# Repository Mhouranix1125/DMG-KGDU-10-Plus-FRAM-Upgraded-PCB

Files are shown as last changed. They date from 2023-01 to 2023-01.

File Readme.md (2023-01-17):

### Welcome! PLEASE READ EVERYTHING!

First: Shoutout to HDR. His work was extremely vital in completing this project. Take a look at his github and check out some of the cool projects he has worked on!

[HDR's Github](https://github.com/HDR)

Second: You do this entire transfer at your own risk. I am not responsible for anything that happens to your game as a result of taking on this project. This is not a beginner task, and should definitely not be taken on as a first-time solder project.  I am not affiliated with any of the companies mentioned here. I do not do this for profit. This is just a neat little thing I decided to work on. 

This project is open source. Users may use this work to iterate, or improve upon it. In doing so, please make sure you follow the Creative Common License linked below. Out of respect for HDR. Do not be a bad actor. your compliance is expected, and appreciated. DMG-KGDU-10 is an original Nintendo PCB design. I take no credit for that. 

[Creative Commons License](https://creativecommons.org/licenses/by-nc-sa/4.0/)

### What is this project about?

In simple terms - This project is an upgraded replacement circuit board for games like Pokémon Gold, Silver, and Crystal. This board utilizes FRAM instead of SRAM so you can save your games without the need for a battery. The battery is still required for the real time clock (RTC) to function. But the good news is you will not lose any save data when the battery does die. This also features a battery retainer, so you can place a CR2025 into the slot without the need for solder tabs. This also enables you to use BRAND NAME batteries. The batteries most users buy for their games have those yellow rings around them and are absolutely terrible and volatile. Brand Name batteries are a more reliable choice and will last MUCH longer. This board was designed with the United States version of the games in mind. I created this board for a few reasons. 

1. SRAM is annoying and I hate that my save data was at the mercy of a simple coin cell battery. This fixes that and allows for a very clean and professional looking mod without wires running all over the place.

2. I see tons of reddit posts of people posting their Pokemon Gold, Silver, or Crystal games in less than stellar condition. Sure, you can use jumper wires, and if you like that, it's all you. Some are beyond repair due to corrosion, broken traces, or just problems that aren't solvable. If the ROM IC, and MBC3 mapper are in good shape. This board will definitely save your game. Your games are not broken if your circuit board is in bad shape!

3. To learn.

### How can I get my hands on these boards?

In order to get your hands on these boards, you will need to download this project zip, or clone it using GIT. One of the files labeled DMG-KGDU-10+_Gerber.zip Is the completed output of the circuit board. There are a few websites you can upload this to in order to get these boards made. they are not that expensive. These are the ones I use often. But feel free to use another if you’re comfortable with them. 

Note: PLEASE ORDER THESE BOARDS WITH THE FOLLOWING SPECIFICATIONS. IF YOU DO NOT ORDER THEM CORRECTLY, THEY WILL NOT WORK, OR WILL NOT FIT!

* Thickness: 0.8mm
* Color: Your choice! Have fun!
* Surface Finish: (ENIG or Immersion Gold. They’re the same thing) , or Hard Gold (expensive). DO NOT USE ANY OTHER OPTION. 
* Castellated Holes: No
* Copper Weight: 1oz is fine. 2oz is nice but not needed.
* Golden Fingers: Yes 
* 45° finger chamfered

1. [JLCPCB:](https://jlcpcb.com/)

o This company is based in China, and has very good pricing on boards so long as you choose either green or purple. I find the best bang for your buck to be 10 boards as it's not that much more expensive than 5.

2. [Elecrow:](https://www.elecrow.com/)

o This company is based in China, the pricing is great, and pricing is similar to JLCPCB and seems consistent across all colors. So I love these guys quite a bit. 

o Note: If using Elecrow, you will need to send them an email to specify that you want Golden Fingers, and beveled 45° finger chamfered. Just give them your order number after you place it. 

3. [Osh Park:](https://oshpark.com/shared_projects/EM2j1Td4)

o Osh Park is a USA based company. Their online gerber viewer and order process is very easy. But your options are very limited. You can only get your boards in their signature deep purple color, which are quite nice. They’re also the most expensive. Their quality is good. You get less PCB’s for your money, and I noticed that it could still take a while for them to come in.

o When you order, choose the option that says: 2 oz copper, 0.8mm thickness and you should be all set. Their ordering process is more streamlined. 

### Materials

You will need the following materials to complete this build. Feel free to source these from wherever you’d like. I recommend [Digikey](https://digikey.com), or [Mouser](https://mouser.com) for most parts. just make sure the sizes for the capacitors and resistors are correct. Double check everything. 

**Bill Of Materials:**

| Reference | Part | Description | Type |
|-|-|-|-|
| U1 | Original ROM | The lower Right chip. This is the chip that holds your game and is needed from the original board. | 44 Pins |
| U2 | MBC3 | Memory Bank Controller. You can only get this from an original Cartridge | LQFP-32 |
| U3 | FM18W08 | 256kbit FRAM | SOIC-28 |
| U4 | BA6129AF | Battery Reset IC. | Get From Original Cartridge or AliExpress | SOIC-8 |
| U5 | 74LVC1G32GV,125 | 2-input OR Gate | TSOP-5 |
| C1, C2, C3, C6, C7 | CL10B104KO8NNNC | 0.1uF Capacitor | 0603 |
| C4, C5 | CL10C150JB8NNNC | 15pF Capacitor | 0603 |
| R1 | RC0603FR-07330KL | 330K Ω Resistor | 0603 |
| R2 | RC0603FR-0710KL | 10K Ω Resistor | 0603 |
| R3 | RC0603FR-071KL | 1K Ω Resistor | 0603 |
| X1 | R26-32.768-12.5-10PPM 20PPM seems to work fine as well. | 32.768 kHz Crystal. | Buy or get from original Cartridge |
| RTC Crystal | Batt 2025 | BK-6219-TR | CR2025 Battery Retainer | Battery Retainer |

Some Tips

1). This should not be your first major solder project. Do not attempt to do this without any practice, or you risk ruining your game. 

2). Everything is pretty straight forward. Make sure you’re good with working on small components. Capacitors and resistors are not easy to solder if you’re new to this. Solder paste and hot air can help you out a lot with that process. 

3). The CR2025 battery may sometimes may not make amazing contact with the large circle pad. This is because it is ever so slightly recessed into the board. This can be fixed in a variety of ways. Super easy, and is pretty much a non issue if you just follow one of the following two ways.

My way of solving this issue is cutting out a thin piece of nickel strip (I try to make it circular in shape, and a bit smaller than the edges of the circle pad. And I lay it down flat and solder it in place before installing the BK-6219-TR retainer. Make sure you solder in the retainer so you can place the battery in from the top side of the board. If you do it upside down, getting the battery in will be annoying because the ROM IC gets in the way. 

Another way, if you don’t want to cover the pad with solder is Makhos way. Makho uses a piece of copper tape on the circle pad, rather than soldering in the nickel strip that I use. It’s nice if you don’t want to get solder on the circle pad. I personally don’t mind but the choice is yours. 

Good luck! Be sure to post your successes, and feel free to ask me any questions!

### Images

# Front

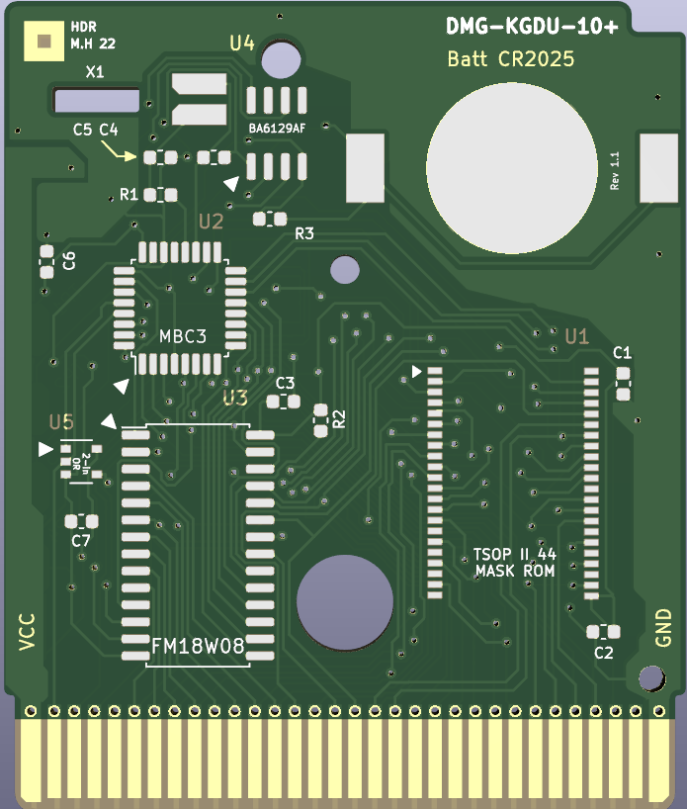
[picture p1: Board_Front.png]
Front


# Back

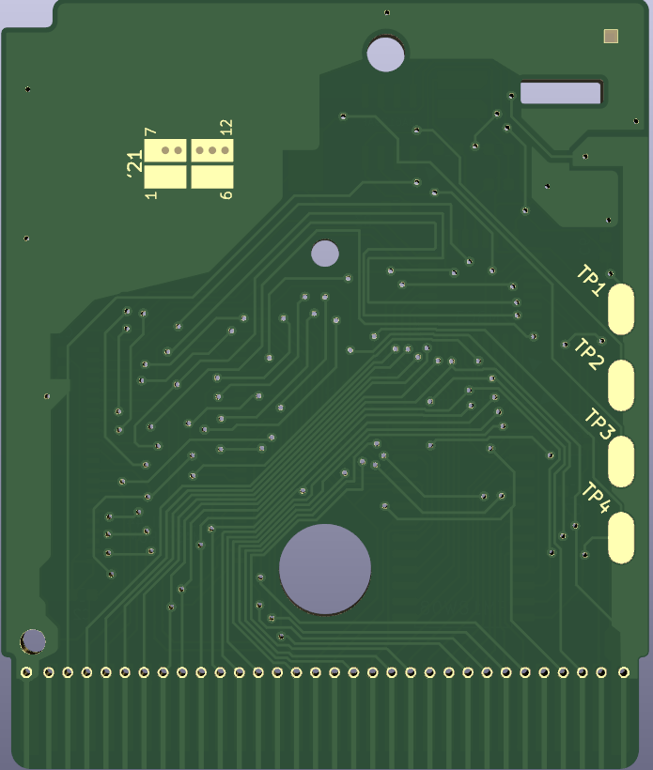
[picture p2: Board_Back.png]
Back


### Changes

Rev 1.1 
- Removed R1 Jumper Resistor. It was not needed.
- Added Text for some parts to help with clarity. The BOM should still be the ultimate source for info. 
- Moved a few capacitors around so they're easier to manage.
- Moved R3 so it would be easier to manage once the battery retainer is soldered in if need be.
- General cleanup.

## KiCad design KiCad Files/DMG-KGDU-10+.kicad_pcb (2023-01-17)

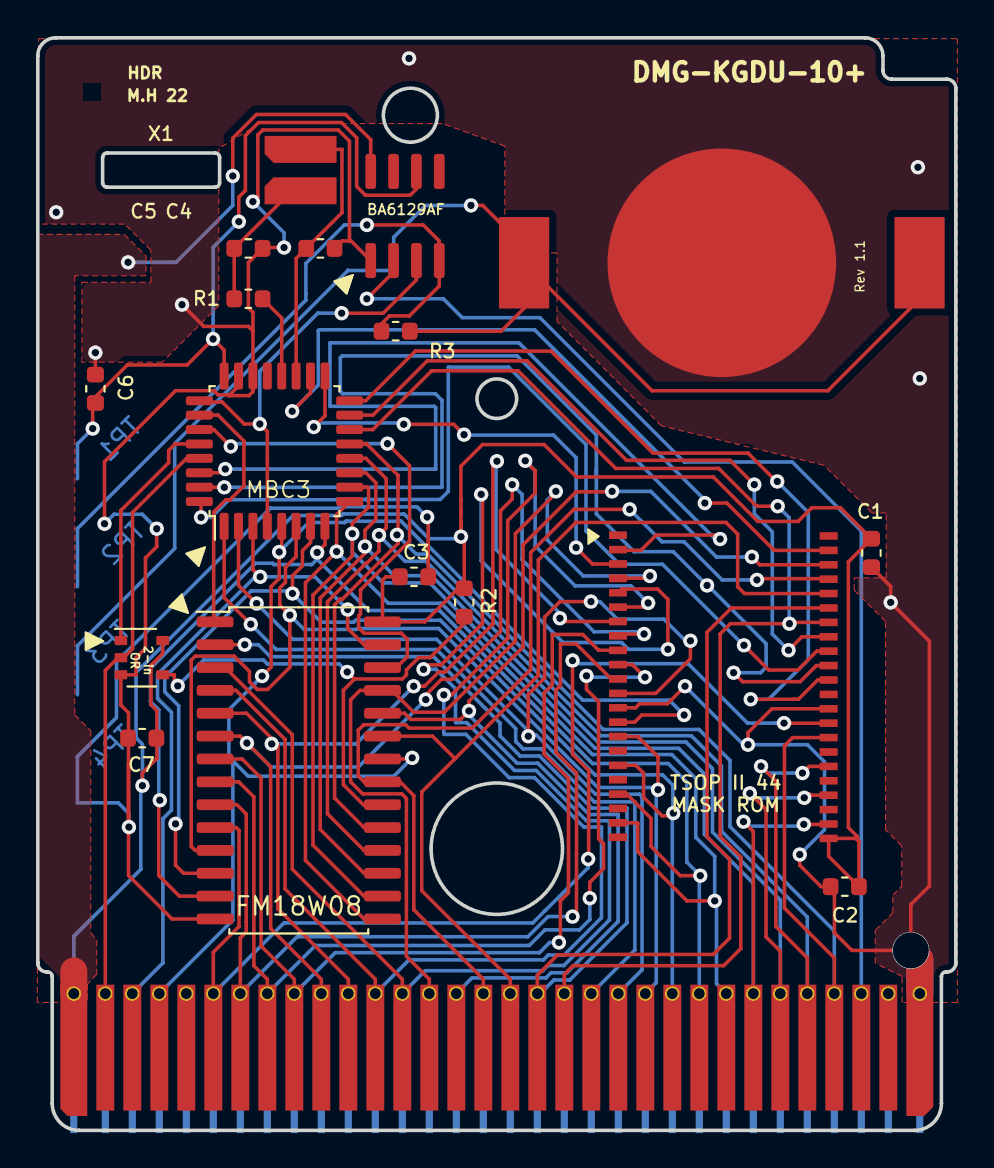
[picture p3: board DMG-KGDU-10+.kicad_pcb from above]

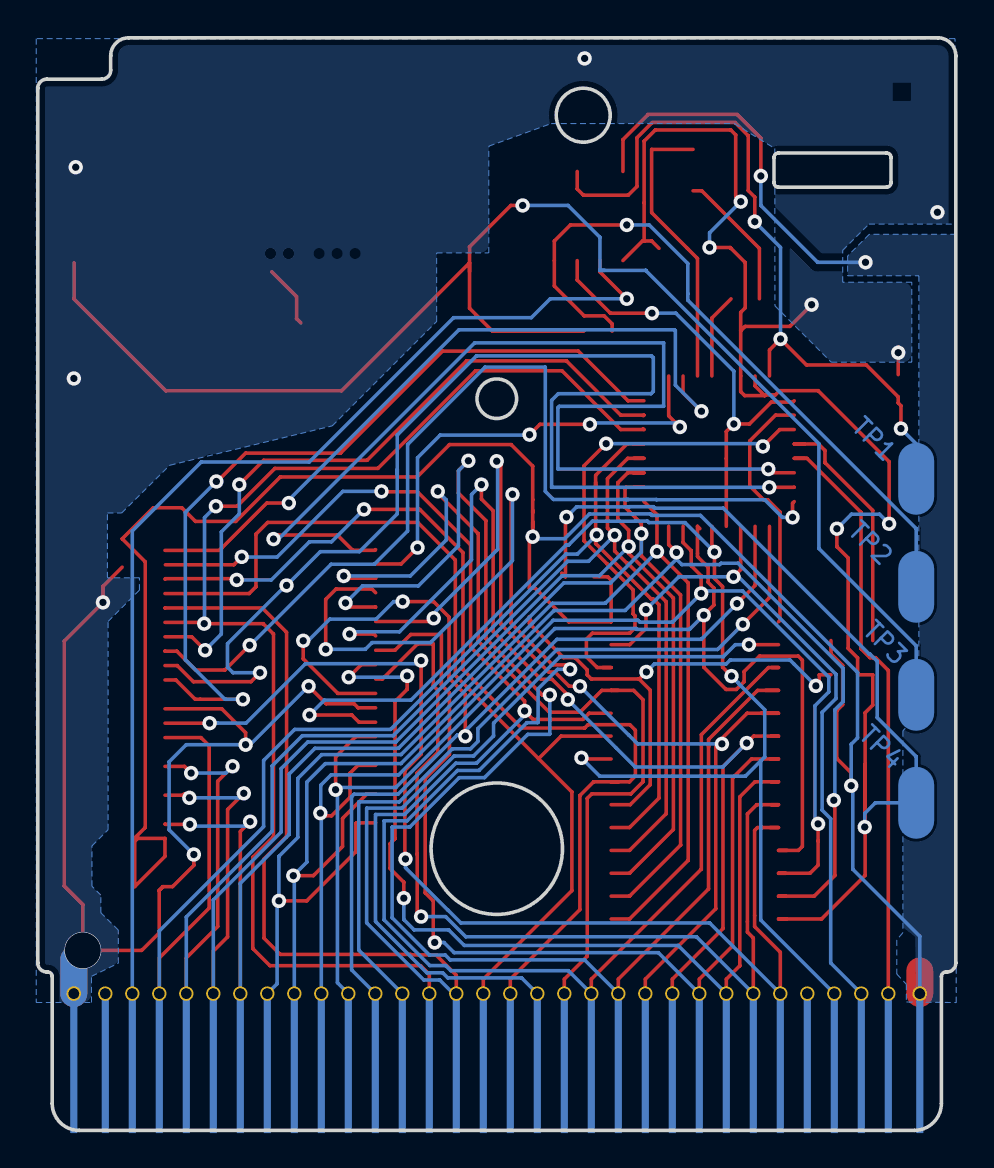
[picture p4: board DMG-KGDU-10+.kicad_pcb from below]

Board: 2 copper layers, 51.0 x 60.7 mm, 25 parts (5 on the bottom side), 48 nets.

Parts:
B1: Battery_Cell; BK-6219-TR
C1, C2, C3, C6, C7: 0.1 uF; C_0603_1608Metric
C4, C5: 15 pF; C_0603_1608Metric
GNDPAD1: Nintendo_3x3_GNDPad
L0: CASTELLATIONS TSOP-II 22P; 22_SMD_PADs
PAD*: GBA-ProductionIndicator
R0: CASTELLATIONS TSOP-II 22P; 22_SMD_PADs
R1: 330Kohm; R_0603_1608Metric
R2: 10 Kohm; R_0603_1608Metric
R3: 1 Kohm; R_0603_1608Metric
TP1: RTC_VOUT; GameBoy_Testpoint
TP2: Battery_Positive_After_Resistor; GameBoy_Testpoint
TP3: Battery_Positive; GameBoy_Testpoint
TP4: Ground; GameBoy_Testpoint
U0: CartBus; GameBoy_GamePak_CGB-002_P1.50mm_Edge
U2: MBC3
U3: FM18W08; SOIC-28W_7.5x17.9mm_P1.27mm
U4: BA6129AF; SOIC-8_3.9x4.9mm_P1.27mm
U5: 74LVC1G32; TSOP-6_1.65x3.05mm_P0.95mm
Y1: Crystal; Resonator_SMD_muRata_CDSCB-2pin_4.5x2.0mm_HandSoldering

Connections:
#CE: R2.1, U3.20, U5.4
A0: R0.14, U0.6, U3.10
A1: L0.12, U0.7, U3.9
A2: L0.13, U0.8, U3.8
A3: L0.14, U0.9, U3.7
A4: L0.15, U0.10, U3.6
A5: L0.16, U0.11, U3.5
A6: L0.17, U0.12, U3.4
A7: L0.18, U0.13, U3.3
A8: L0.19, U0.14, U3.25
A9: R0.3, U0.15, U3.24
A10: R0.4, U0.16, U3.21
A11: R0.5, U0.17, U3.23
A12: R0.6, U0.18, U3.2
A13: R0.7, U0.19, U2.14
A14: U0.20, U2.1
A15: L0.11, U0.21, U2.2
AA13: U2.27, U3.26
AA14: U2.26, U3.1
BT+: B1.1, R3.1, TP3.1
CLK: U0.2, U2.29, U5.2
D0: L0.8, U0.22, U2.6, U3.11
D1: L0.6, U0.23, U2.7, U3.12
D2: L0.4, U0.24, U2.8, U3.13
D3: L0.2, U0.25, U2.9, U3.15
D4: R0.21, U0.26, U2.10, U3.16
D5: R0.19, U0.27, U2.11, U3.17
D6: R0.17, U0.28, U2.12, U3.18
D7: R0.15, U0.29, U2.13, U3.19
GND: B1.2, C1.1, C2.2, C3.1, C4.2, C5.1, C6.2, C7.1, L0.10, R0.13, TP4.1, U0.32, U2.22, U2.23, U3.14, U4.1, U5.3
unnamed: C5.2, R1.2, Y1.1
PWR: C6.1, TP1.1, U2.24, U4.6
RA14: R0.8, U2.15
RA15: R0.9, U2.32
RA16: R0.10, U2.31
RA17: R0.11, U2.16
RA18: L0.20, U2.17
RA19: L0.21, U2.30
RA20: R0.2, U2.18
RESET: U0.30, U4.2
VCC: C1.2, C2.1, C3.2, C7.2, R0.22, R2.2, U0.1, U3.28, U4.8, U5.6
Vbatt: R3.2, TP2.1, U4.4
XIN: C4.1, U2.19, Y1.2
XOUT: R1.1, U2.20
\RAMCS: U2.28, U5.1
\RD: L0.9, U0.4, U2.5, U3.22
\RST: U2.4, U2.25, U4.3
\WR: U0.3, U2.3, U3.27

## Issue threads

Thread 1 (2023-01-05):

BOM Alternatives and Notes

Chase-san, 2023-01-05:
In case some of the rarer parts are out of stock, I have made up a list of otherwise similar parts for reference purposes. Every part links directly to the relevant datasheet. I hve also included parts that are not recommended despite appearing compatible.

There are so many 0603 resistors and capacitors in existence I don't feel that those require a listing here.

| Ref | Manufacturer | Part | Notes |
| --- | ------------ | ---- | ------ |
| U3 | infineon | [FM28V020](https://www.mouser.com/datasheet/2/196/CYPR_S_A0011167037_1-3004858.pdf) | Not recommended. This chip has an absolute maximum voltage of 4.5v. A gameboy cart operates at a nominal voltage of 5v. It will likely work but its life will be drastically reduced. |
| U3 | infineon | [FM1808B](https://www.mouser.com/datasheet/2/196/CYPR_S_A0011134546_1-3004721.pdf) | Inferior. Has a lower memory endurance but is otherwise compatible. |
| X1 | ESC | [ECS-.327-12.5-13X-C](https://www.mouser.com/datasheet/2/122/ECS_3x8X_2x6X_1X5X-5572.pdf) | Nearly identical. |
| X1 | ABRACON | [AB26TRB-32.768KHZ-T](https://www.mouser.com/datasheet/2/3/AB26TRB-2089610.pdf) | Somewhat smaller, and has legs that will need to be straightened before install. Has bulge at base of crystal. |
| X1 | PERICOM | [G13270009](https://www.mouser.com/datasheet/2/115/Diodes_08122021_G13270009-2509648.pdf) | Slightly wider at base rather than a perfect cylinder. |
| Batt 2025 | Linx | [BAT-HLD-001 ](https://www.mouser.com/datasheet/2/238/LNNC_S_A0002913840_1-2550745.pdf) | Not recommended despite nearly identical footprint. At 4.2mm in height this exceeds the maximum case clearance. |
| Batt 2025 | Linx | [BAT-HLD-002](https://www.mouser.com/datasheet/2/238/bat_hld_002_smt-1659519.pdf) | Nearly identical footprint, but shorter. Designed for CR2016 batteries. Technically tall enough to fit a CR2025. |

These are the Ram Protection ICs. Any of these will (probably) work. There are many revisions of games so the same game may have come with more than one of these. Chip Label is what is printed physically on the chip, a # can be any character. I included where I found this chip just to help relieve any stress from using an odd chip.

| Ref | Manufacturer | Part | Chip Label | Found In | Notes |
| --- | ------------ | ---- | ---------- | ------- | ------ |
| U4 | MITSUMI | [MM1143A](https://www.digchip.com/datasheets/parts/datasheet/304/MM1134-pdf.php) | M&nbsp;### 134A | Pokemon Gold (Europe, USA), Pokemon Crystal (Aus, USA&nbsp;Rev&nbsp;1) | Recommended. Common. Used by almost everything. Probably the reference IC since it's printed on the PCB. |
| U4 | MITSUMI | [MM1026A](http://www.datasheetq.com/datasheet-download/894569/1/Mitsumi/MM1026) | M&nbsp;### 26A | Pocket Monsters Green (Jap), Pocket Monsters Pikachu (Jap), Pokemon Blue (USA) | Compatible. Less common. Never used on GSC as far as I can find. |
| U4 | ROHM | [BA6129AF](https://www.mouser.com/datasheet/2/348/Rohm-BA6129AF_BA6162_BA6162F-1201632.pdf) | 6129A #### | Pokemon Red (USA), Pokemon Silver (USA) | Compatible. Less common. |
| U4 | ROHM | BA6735 | 6735 #### | Pokemon Silver (USA), Pokemon Crystal (USA) | Compatible. Less common. |

MelonGx, 2023-12-20:
I have one question:

Japanese FRAM modders said only FM1808-70-SG (the former model of FM1808B) was compatible with Nintendo 64 (Stadium series).

Does anyone test this for FM18W08 / FM1808B?

Closed 2023-01-13.

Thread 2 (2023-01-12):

Game runs, clock does not.

Chase-san, 2023-01-12:
BOM

- 1x FM18W08-SG
- 1x DMG-KGDU-10+, from JLCPCB
- 1x 771-LVC1G32GV125
- 5x 187-CL10B104KO8NNNC
- 2x 187-CL10C150JB8NNNC
- 1x 603-RC0603FR-07330KL
- 1x 603-RC0603FR-0710KL
- 1x 603-RC0603FR-071KL
- 1x 603-AC0603JR-070RL
- 1x 520-S-.32712.513XC
- 1x 712-BAT-HLD-002-SMT
- 1x 658-CR2025 (Panasonic)
- 1x MX23C1603 (DMG-AAXE-0), from silver cart
- 1x BA6735, from silver cart
- 1x MBC3-B, from silver cart

Each part was placed in groups, meaning only one type of 0603 was loose at a time to prevent mixups. All work was performed on an ESD mat.

Game runs, clock does not. Any thoughts? I have other Ram Protect ICs and a few MBC3-As around.

Normal Images
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

UV Images
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

Mhouranix1125, 2023-01-12:
@Chase-san  Hey man. Very good job putting it together.

So the one thing I know that will stop thr clock is if you didn't put copper tape on the giant circle pad under the battery holder. Alternatively you could solder in a small nickel strip. This happens because the battery pad is slightly indented into the board. Same thing happened to me. I've since got it running on my gold silver and crystal versions. Let me know how it goes

Mhouranix1125, 2023-01-12:
If your battery is giving you voltage across the board then that should be fine. The specs for your rtc crystal seem similar enough with the only real difference I see being the series (R26 on mine).

Humor me. Don't take your working silver completely apart. I just want you to borrow the crystal oscillator from the inside of it and try it out. Let's rule out all potential issues. (I do still have to go through your full list)

Mhouranix1125, 2023-01-12:
@Chase-san

Hmm. Everything should work here. The oscillator works in the original cart so that's good. The battery retainer causing the battery to mount tightly into the board may cause issues. It's a long shot though. Could just be grasping at straws. Why not try a properly sized CR2016 battery. It could be mounting pressure.

I would also reflow and make sure to press down a little on the top section of pins on the mbc3.

And It may just be me but I'm looking at the pictures you posted and why does it look like there are some broken traces above the mounting pads for the rtc crystal? Am I crazy or do those look cut?

If you'd like we can jump on a discord call as well while we troubleshoot this sometime. I'd love to see this workout for you.

Mhouranix1125, 2023-01-12:
Sent. I'm on right now. If you want we can have a quick chat.

Mhouranix1125, 2023-01-13:
The issue is solved. User had a few cold solder joints. The clock is now running.

Closed 2023-01-13.

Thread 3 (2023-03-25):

Game crashes after several inputs

ewaynem, 2023-03-25:
BOM:

- 1x   DMG-KGDU-10+, from JLCPCB
- 1x   FM18W08SG
- 1x   MX23C1603-12A (DMG-AAXE-0), from original Silver cartridge
- 1x   MBC3-B, from original Silver cartridge
- 1x   M030 134A, from original Silver cartridge
- 1x   R26-32.768-12.5-10PPM, from original Silver cartridge
- 5x   187-CL10B104KO8NNNC, from Mouser
- 2x   187-CL10C150JB8NNNC, from Mouser
- 1x   603-RC0603FR-07330KL, from Mouser
- 1x   603-RC0603FR-0710KL, from Mouser
- 1x   603-RC0603FR-071KL, from Mouser
- 1x   712-BAT-6219-TR, from Digikey
- 1x   CR2025 (Energizer)

I have tested this on two individual boards, one running an original Pokemon Silver rom, and one running an original Trade & Battle: Card Hero rom.  I have not tested the RTC on the Card Hero, but the RTC on the SIlver functions properly and has been running for several days without failure.  The FRAM chip on the Silver functions and holds a save.

Each part was soldered on using hot air and flux.  They were placed in one at a time to prevent mix up.  I have tested the resistors to insure they are not in the incorrect positions.  I do not have a way to test the capacitors, though I am certain they are placed correctly.  Touchup was done with a soldering iron and more flux.  There are no bridges.

Sometimes the games run for a minute before crashing, sometimes they crash before getting past the title screen.  They will both either freeze entirely, crash to a white screen, or reset to the title menu with corrupted sprites and colors.  Most often they crash after A or B inputs or D-pad inputs.  This occurs in both an original Gameboy Color and an original Gameboy Advance SP.  I haven't yet tested whether this occurs in a Gameboy Advance or a Gamecube Gameboy Player.

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

Mhouranix1125, 2023-03-25:
One thing that usually runs consistent when people run into issues attempting to move things from an OEM board to one of my boards is the initial use of solder paste and hot air.

Upon inspecting your board, it also looks like you were pretty rough with the iron and scraped around while soldering in the chip (if you look at some of the pads you can see you've dug up and tinned the traces in several areas).

When I move things to this board, I have found that you should only use solder paste and hot air on resistors and capacitors. I always put those in first.

Next I only use a soldering iron and Flux to put the chips in. The issues you're talking about pertaining to the white screens amd crashing usually happen when the FRAM is not soldered in properly.

Mhouranix1125, 2023-03-25:
Also. What or gate are you using right there? It has a Y32 symbol on it from what I can see. Can you send me the link you used to purchase that?

ewaynem, 2023-03-25:
Here are the links to the parts I ordered:

https://www.mouser.com/ProductDetail/771-LVC1G32GV125
https://www.mouser.com/ProductDetail/187-CL10B104KO8NNNC
https://www.mouser.com/ProductDetail/187-CL10C150JB8NNNC
https://www.mouser.com/ProductDetail/603-RC0603FR-07330KL
https://www.mouser.com/ProductDetail/603-RC0603FR-0710KL
https://www.mouser.com/ProductDetail/603-RC0603FR-071KL

ewaynem, 2023-03-25:
Also, I tested the Pokemon Silver on the Gamecube Gameboy Player for about ten minutes or so, and it didn't crash.  This is the longest the board went without crashing.

Mhouranix1125, 2023-03-25:
Those parts look fine.

The issue is likely in the solder work. I don't know your level of expertise but I see a lot of solder mask scraped off near pads on both boards. I see some traces that are exposed and tinned. On the card game, why is the board all white on the left hand side?

I would reattempt this on fresh boards and I wouldn't use any solder paste. Your iron may be a little too hot as well and you may be pressing a bit hard.

Mhouranix1125, 2023-03-25:
Can you send me the specifications of the board you ordered from JLC? Are they the correct thickness?

ewaynem, 2023-03-26:
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

The card game board is white because of the glare from the light.

Mhouranix1125, 2023-03-26:
Got it. Reattempt this on fresh boards. Don't use solder paste.

If it doesn't work you can send one or both games to me and I will put them together for you at no cost other than shipping. I will require 2 fresh boards from you on your end. This will help rule out issues with your board.

If I find that your boards are faulty I will use two of my own and ensure you have working games.

Let me know if this interests you. I highly encourage you try it out again on your own though.

Mhouranix1125, 2023-03-27:
@ewaynem checking in. Have you attempted the transfer to a new board?

ewaynem, 2023-03-27:
I have attempted a new board with minimal to no success.  Now getting a corrupted Nintendo logo at the Gameboy screen, which I'm certain is a result of my, shall we say, limited soldering skills.  I even grabbed another mapper chip to ensure that it wasn't a hardware issue.  I've inspected the pins of each chip and none of them are loose.

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

Mhouranix1125, 2023-03-27:
> I have attempted a new board with minimal to no success. Now getting a corrupted Nintendo logo at the Gameboy screen, which I'm certain is a result of my, shall we say, limited soldering skills. I even grabbed another mapper chip to ensure that it wasn't a hardware issue. I've inspected the pins of each chip and none of them are loose.
>
> 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

Yes. The corrupted nintendo logo can happen because chips are incorrectly soldered. Your MBC3 looks like it needs more solder. It doesn't look like it's making a reliable connection. Where did you get the FRAM chips from?

You shouldn't be attempting this if you're pretty new to soldering, though.

It might be a better idea to practice on some cheap throw away games. I would buy two copies of a game like bugs life and practice transferring rom chips over.

Or you can buy Japanese versions of pokemon gold and silver and swap mask roms until you get it right.

ewaynem, 2023-03-27:
That's the funny thing, I have swapped roms and SRAM and FRAM chips before with great success.  I got the FRAM chips from Aliexpress and ebay.

Mhouranix1125, 2023-03-27:
> That's the funny thing, I have swapped roms and SRAM and FRAM chips before with great success. I got the FRAM chips from Aliexpress and ebay.

If you ever feel like letting me take a swing at helping you with this, let me know.

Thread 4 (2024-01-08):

Bill of Materials correct?

nillawafers11, 2024-01-08:
Hi there, just wanna make sure I'm getting the correct parts for this upgraded PCB. I've got them all in my Digikey cart, and plan on swapping my beat up copy of Pokemon Silver to the new board. Below is the list of parts I have in my cart:

- [BK-6219-CT-ND](https://www.digikey.com/en/products/detail/mpd-memory-protection-devices/BK-6219-TR/8119239) Qt. 1
- [311-1.00KHRCT-ND](https://www.digikey.com/en/products/detail/yageo/RC0603FR-071KL/726843) Qt. 1
- [311-10.0KHRCT-ND](https://www.digikey.com/en/products/detail/yageo/RC0603FR-0710KL/726880) Qt. 1
- [311-330KHRCT-ND](https://www.digikey.com/en/products/detail/yageo/RC0603FR-07330KL/727163) Qt. 1
- [1276-1296-1-ND](https://www.digikey.com/en/products/detail/samsung-electro-mechanics/CL10C150JB8NNNC/3886954) Qt. 2
- [1727-3101-1-ND](https://www.digikey.com/en/products/detail/nexperia-usa-inc/74LVC1G32GV-125/946687) Qt. 1
- [448-FM18W08-SGTRCT-ND](https://www.digikey.com/en/products/detail/infineon-technologies/FM18W08-SGTR/4090359) Qt. 1
- [1276-1005-1-ND](https://www.digikey.com/en/products/detail/samsung-electro-mechanics/CL10B104KO8NNNC/3886663) Qt. 5

Thank you!

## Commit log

2022-10-20 Rerouted tracks to work with an original Mask Rom
    [Mbc3-Flash-Storage-PCB.kicad_pcb]
2022-11-11 Replaced 3 input or-gate with a 2-input one.
    [Mbc3-Flash-Storage-PCB.kicad_pcb]
2022-11-30 Added stuff for public use.
    [DMG-KGDU-10+.kicad_pcb]
2023-01-17 Rev 1.1 update
    [DMG-KGDU-10+-B_Cu.gbr, DMG-KGDU-10+-B_Fab.gbr, DMG-KGDU-10+-B_Mask.gbr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]
